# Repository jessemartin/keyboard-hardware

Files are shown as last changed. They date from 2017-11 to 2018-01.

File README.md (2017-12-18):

Wireless Keyboard Project: Hardware
===================================

These are [Eagle](https://www.autodesk.com/products/eagle/overview) design files for PCBs used in my wireless keyboard project.

Engineering Overview
--------------------
Each keyboard section runs a [Nordic nRF51822](https://www.nordicsemi.com/eng/Products/Bluetooth-low-energy/nRF51822) in the [Waveshare core51822-b](https://www.waveshare.com/core51822-b.htm) package, powered by a lithium ion battery.

Instead of using a traditional matrix that requires constant scanning (and thereby constant power usage), each key is connected to its own dedicated pin. This way, the chip can enter sleep until interrupted by a key press.

When a key press occurs, it is first debounced to prevent the mechanical switch from generating extra key presses. After that, the pressed keys are collected and transmitted through the [Gazell protocol](https://infocenter.nordicsemi.com/index.jsp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) to the receiver.

The receiver transforms the pressed keys into a matrix and passes that off the the [ATmega32U4 Pro Micro](https://www.sparkfun.com/products/12640), which runs [QMK firmware](https://github.com/qmk/qmk_firmware/). The Pro Micro sends the signal over USB to the computer as input.

Keyboard Layout
---------------
http://www.keyboard-layout-editor.com/#/gists/4d522280e8e3315902466de2c982f663
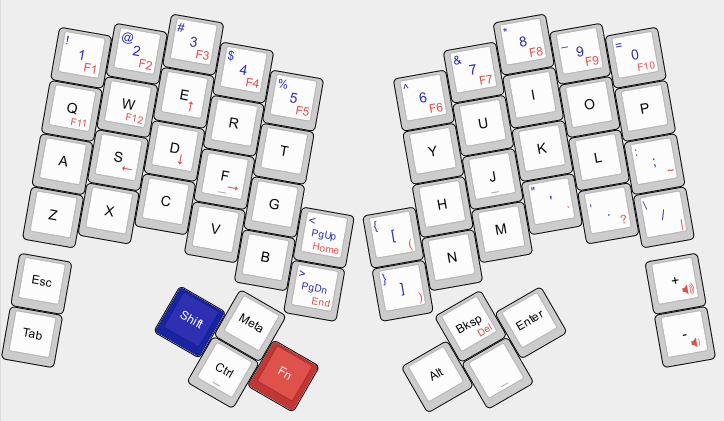
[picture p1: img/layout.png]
Layout


Folder Structure
----------------
 - `3d` contains [SketchUp](https://app.sketchup.com/app) renderings of what the final product could look like. These are not dimensionally accurate.
 - `fab` contains design rules and CAM settings for [DirtyPCBs](https://dirtypcbs.com/store/pcbs) and [OSH Park](https://oshpark.com/)
 - `lib` contains device libraries that are used by the `receiver` and `keyboard` projects.

PCB Fab Specifications
----------------------
* FR4 fiberglass
* 2 layer
* 1.6mm thickness

Keyboard PCBs
-------------

A single, reversible board is used for each keyboard half. The top of the board is used for the left half, and the bottom for the right half:

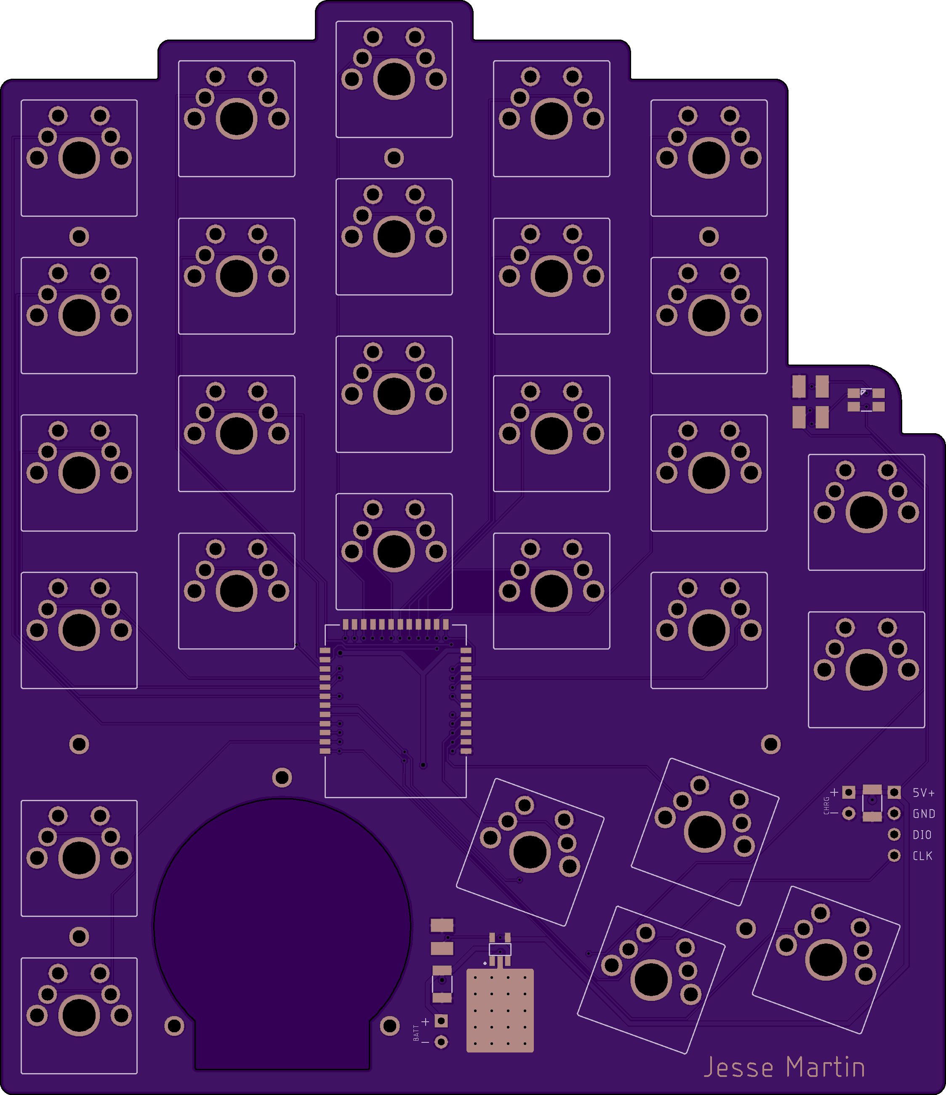
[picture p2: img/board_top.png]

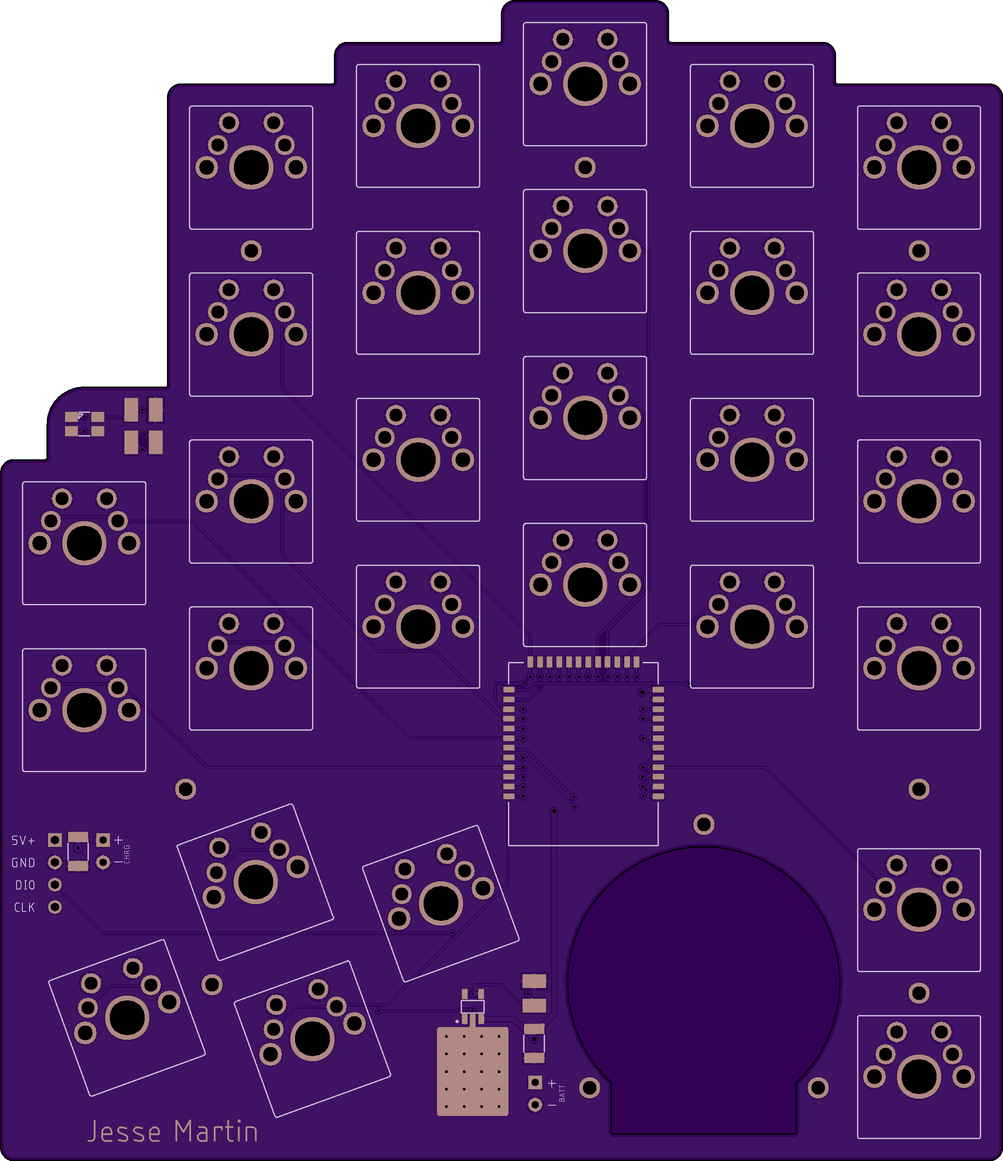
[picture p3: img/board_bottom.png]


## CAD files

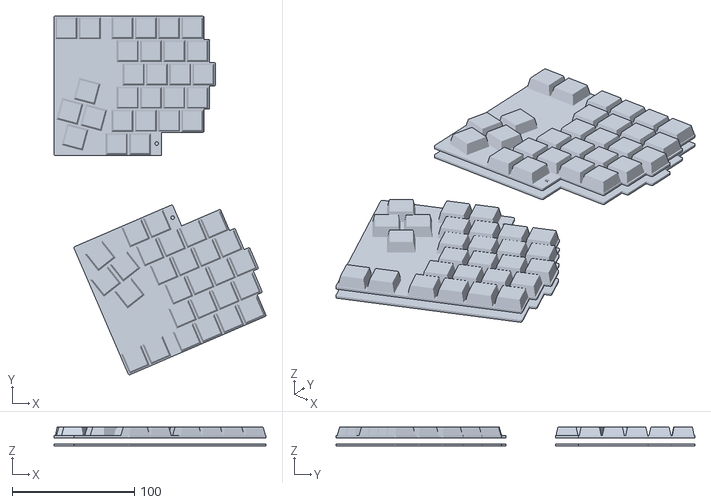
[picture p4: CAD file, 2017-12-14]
3d/keyboard.stl
173.2 x 293.2 x 15.3

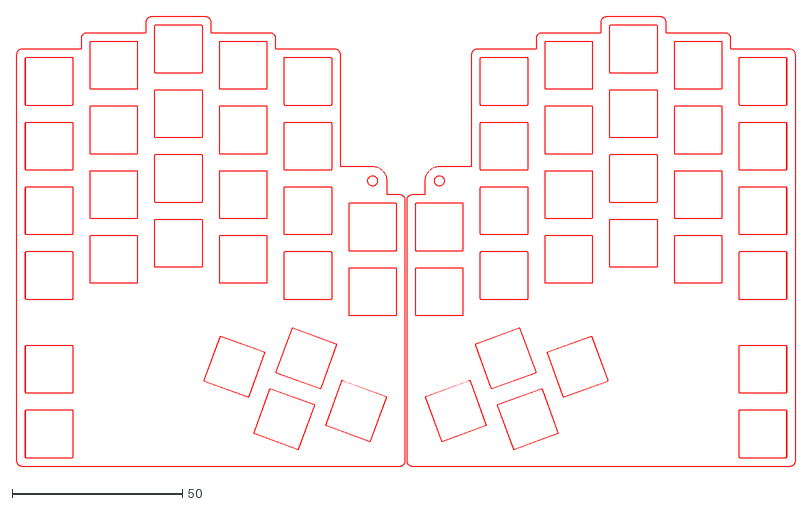
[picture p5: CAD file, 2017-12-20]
keyboard/plate.dxf
228.8 x 132.2

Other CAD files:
3d/keyboard.skp

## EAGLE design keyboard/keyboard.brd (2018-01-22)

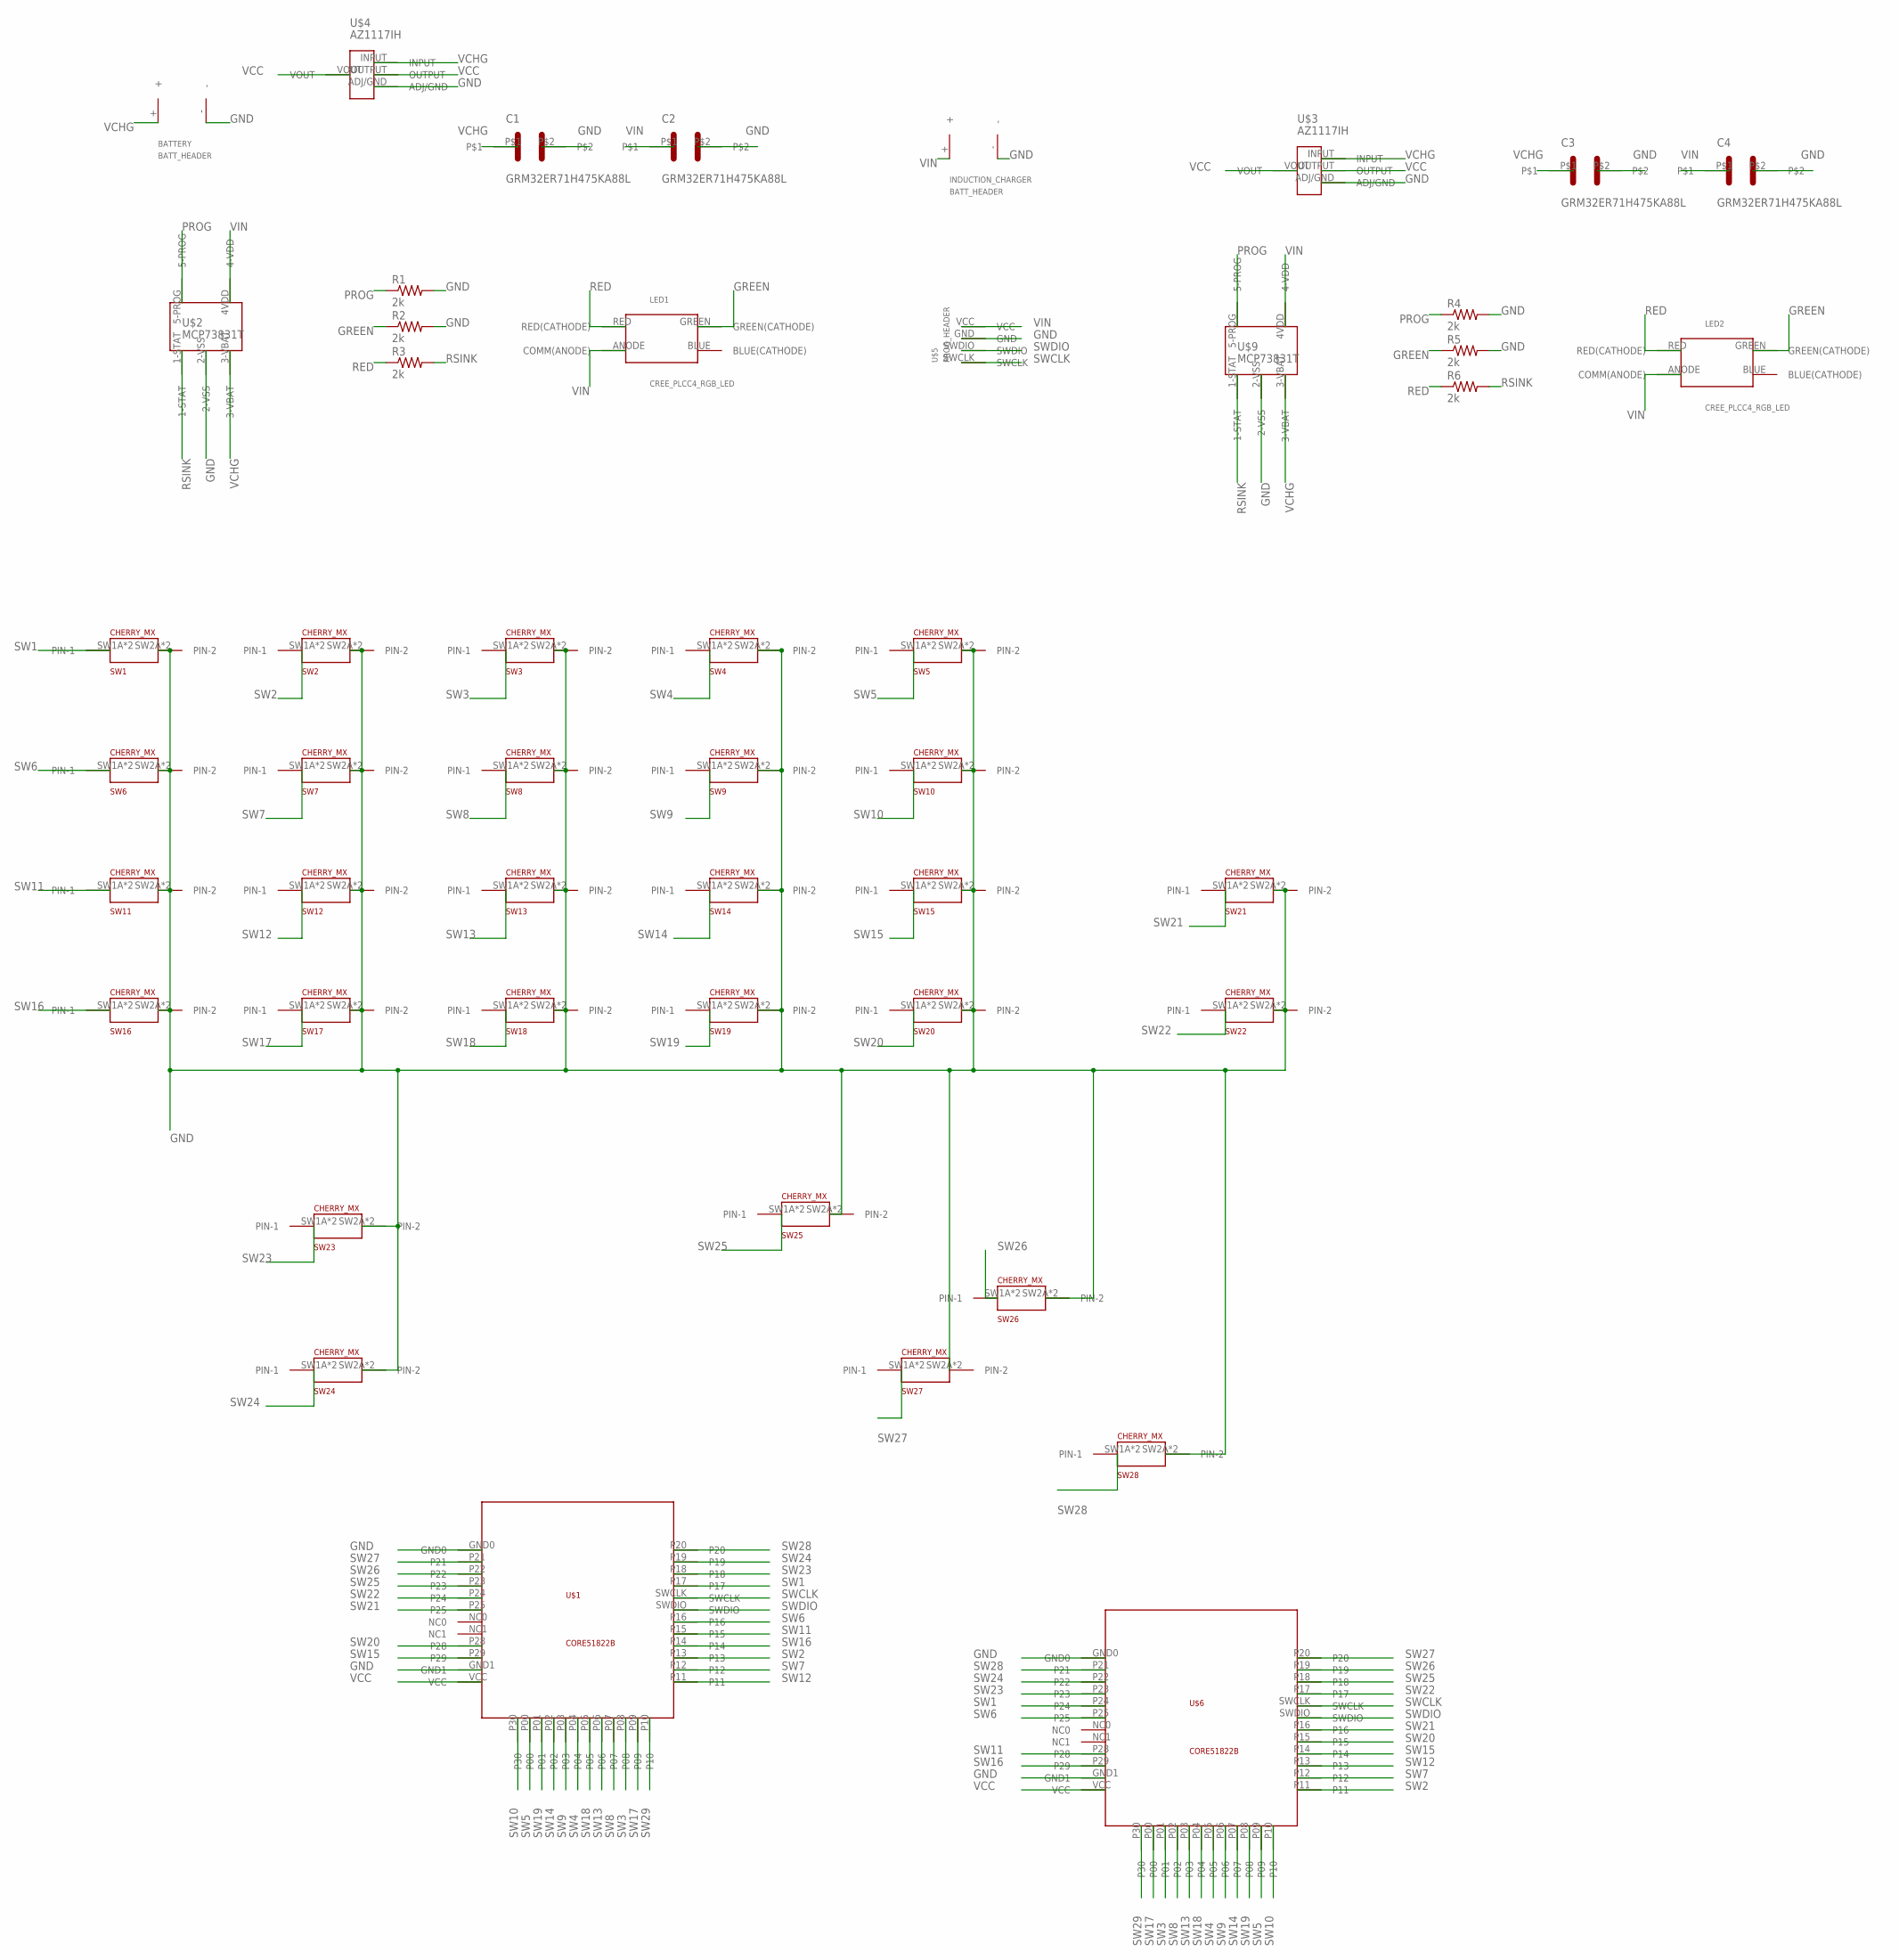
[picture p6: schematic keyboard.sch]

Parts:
BATTERY: BATT_HEADER
C1, C2, C3, C4: GRM32ER71H475KA88L
INDUCTION_CHARGER: BATT_HEADER
LED1, LED2: CREE_PLCC4_RGB_LED; 4-PLCC
R1, R2, R3, R4, R5, R6: 2k; R1210
SW1, SW2, SW3, SW4, SW5, SW6, SW7, SW8, SW9, SW10, SW11, SW12, SW13, SW14, SW15, SW16, SW17, SW18, SW19, SW20, SW21, SW22, SW23, SW24, SW25, SW26, SW27, SW28: CHERRY_MX
U$1, U$6: CORE51822B
U$2, U$9: MCP73831T
U$3, U$4: AZ1117IH
U$5: PROG_HEADER

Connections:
GND: BATTERY.-, C1.P$2, C2.P$2, C3.P$2, C4.P$2, INDUCTION_CHARGER.-, R1.2, R2.2, R4.2, R5.2, SW1.SW2A (PIN-2), SW1.SW2B (PIN-2), SW2.SW2A (PIN-2), SW2.SW2B (PIN-2), SW3.SW2A (PIN-2), SW3.SW2B (PIN-2), SW4.SW2A (PIN-2), SW4.SW2B (PIN-2), SW5.SW2A (PIN-2), SW5.SW2B (PIN-2), SW6.SW2A (PIN-2), SW6.SW2B (PIN-2), SW7.SW2A (PIN-2), SW7.SW2B (PIN-2), SW8.SW2A (PIN-2), SW8.SW2B (PIN-2), SW9.SW2A (PIN-2), SW9.SW2B (PIN-2), SW10.SW2A (PIN-2), SW10.SW2B (PIN-2), SW11.SW2A (PIN-2), SW11.SW2B (PIN-2), SW12.SW2A (PIN-2), SW12.SW2B (PIN-2), SW13.SW2A (PIN-2), SW13.SW2B (PIN-2), SW14.SW2A (PIN-2), SW14.SW2B (PIN-2), SW15.SW2A (PIN-2), SW15.SW2B (PIN-2), SW16.SW2A (PIN-2), SW16.SW2B (PIN-2), SW17.SW2A (PIN-2), SW17.SW2B (PIN-2), SW18.SW2A (PIN-2), SW18.SW2B (PIN-2), SW19.SW2A (PIN-2), SW19.SW2B (PIN-2), SW20.SW2A (PIN-2), SW20.SW2B (PIN-2), SW21.SW2A (PIN-2), SW21.SW2B (PIN-2), SW22.SW2A (PIN-2), SW22.SW2B (PIN-2), SW23.SW2A (PIN-2), SW23.SW2B (PIN-2), SW24.SW2A (PIN-2), SW24.SW2B (PIN-2), SW25.SW2A (PIN-2), SW25.SW2B (PIN-2), SW26.SW2A (PIN-2), SW26.SW2B (PIN-2), SW27.SW2A (PIN-2), SW27.SW2B (PIN-2), SW28.SW2A (PIN-2), SW28.SW2B (PIN-2), U$1.GND0, U$1.GND1, U$2.2-VSS, U$3.ADJ/GND, U$4.ADJ/GND, U$5.GND, U$6.GND0, U$6.GND1, U$9.2-VSS
GREEN: LED1.GREEN (GREEN(CATHODE)), LED2.GREEN (GREEN(CATHODE)), R2.1, R5.1
PROG: R1.1, R4.1, U$2.5-PROG, U$9.5-PROG
RED: LED1.RED (RED(CATHODE)), LED2.RED (RED(CATHODE)), R3.1, R6.1
RSINK: R3.2, R6.2, U$2.1-STAT, U$9.1-STAT
SW1: SW1.SW1A (PIN-1), SW1.SW1B (PIN-1), U$1.P17, U$6.P24
SW2: SW2.SW1A (PIN-1), SW2.SW1B (PIN-1), U$1.P13, U$6.P11
SW3: SW3.SW1A (PIN-1), SW3.SW1B (PIN-1), U$1.P08, U$6.P01
SW4: SW4.SW1A (PIN-1), SW4.SW1B (PIN-1), U$1.P04, U$6.P05
SW5: SW5.SW1A (PIN-1), SW5.SW1B (PIN-1), U$1.P00, U$6.P09
SW6: SW6.SW1A (PIN-1), SW6.SW1B (PIN-1), U$1.P16, U$6.P25
SW7: SW7.SW1A (PIN-1), SW7.SW1B (PIN-1), U$1.P12, U$6.P12
SW8: SW8.SW1A (PIN-1), SW8.SW1B (PIN-1), U$1.P07, U$6.P02
SW9: SW9.SW1A (PIN-1), SW9.SW1B (PIN-1), U$1.P03, U$6.P06
SW10: SW10.SW1A (PIN-1), SW10.SW1B (PIN-1), U$1.P30, U$6.P10
SW11: SW11.SW1A (PIN-1), SW11.SW1B (PIN-1), U$1.P15, U$6.P28
SW12: SW12.SW1A (PIN-1), SW12.SW1B (PIN-1), U$1.P11, U$6.P13
SW13: SW13.SW1A (PIN-1), SW13.SW1B (PIN-1), U$1.P06, U$6.P03
SW14: SW14.SW1A (PIN-1), SW14.SW1B (PIN-1), U$1.P02, U$6.P07
SW15: SW15.SW1A (PIN-1), SW15.SW1B (PIN-1), U$1.P29, U$6.P14
SW16: SW16.SW1A (PIN-1), SW16.SW1B (PIN-1), U$1.P14, U$6.P29
SW17: SW17.SW1A (PIN-1), SW17.SW1B (PIN-1), U$1.P09, U$6.P00
SW18: SW18.SW1A (PIN-1), SW18.SW1B (PIN-1), U$1.P05, U$6.P04
SW19: SW19.SW1A (PIN-1), SW19.SW1B (PIN-1), U$1.P01, U$6.P08
SW20: SW20.SW1A (PIN-1), SW20.SW1B (PIN-1), U$1.P28, U$6.P15
SW21: SW21.SW1A (PIN-1), SW21.SW1B (PIN-1), U$1.P25, U$6.P16
SW22: SW22.SW1A (PIN-1), SW22.SW1B (PIN-1), U$1.P24, U$6.P17
SW23: SW23.SW1A (PIN-1), SW23.SW1B (PIN-1), U$1.P18, U$6.P23
SW24: SW24.SW1A (PIN-1), SW24.SW1B (PIN-1), U$1.P19, U$6.P22
SW25: SW25.SW1A (PIN-1), SW25.SW1B (PIN-1), U$1.P23, U$6.P18
SW26: SW26.SW1A (PIN-1), SW26.SW1B (PIN-1), U$1.P22, U$6.P19
SW27: SW27.SW1A (PIN-1), SW27.SW1B (PIN-1), U$1.P21, U$6.P20
SW28: SW28.SW1A (PIN-1), SW28.SW1B (PIN-1), U$1.P20, U$6.P21
SW29: U$1.P10, U$6.P30
SWCLK: U$1.SWCLK, U$5.SWCLK, U$6.SWCLK
SWDIO: U$1.SWDIO, U$5.SWDIO, U$6.SWDIO
VCC: U$1.VCC, U$3.OUTPUT, U$3.VOUT, U$4.OUTPUT, U$4.VOUT, U$6.VCC
VCHG: BATTERY.+, C1.P$1, C3.P$1, U$2.3-VBAT, U$3.INPUT, U$4.INPUT, U$9.3-VBAT
VIN: C2.P$1, C4.P$1, INDUCTION_CHARGER.+, LED1.ANODE (COMM(ANODE)), LED2.ANODE (COMM(ANODE)), U$2.4VDD (4-VDD), U$5.VCC, U$9.4VDD (4-VDD)

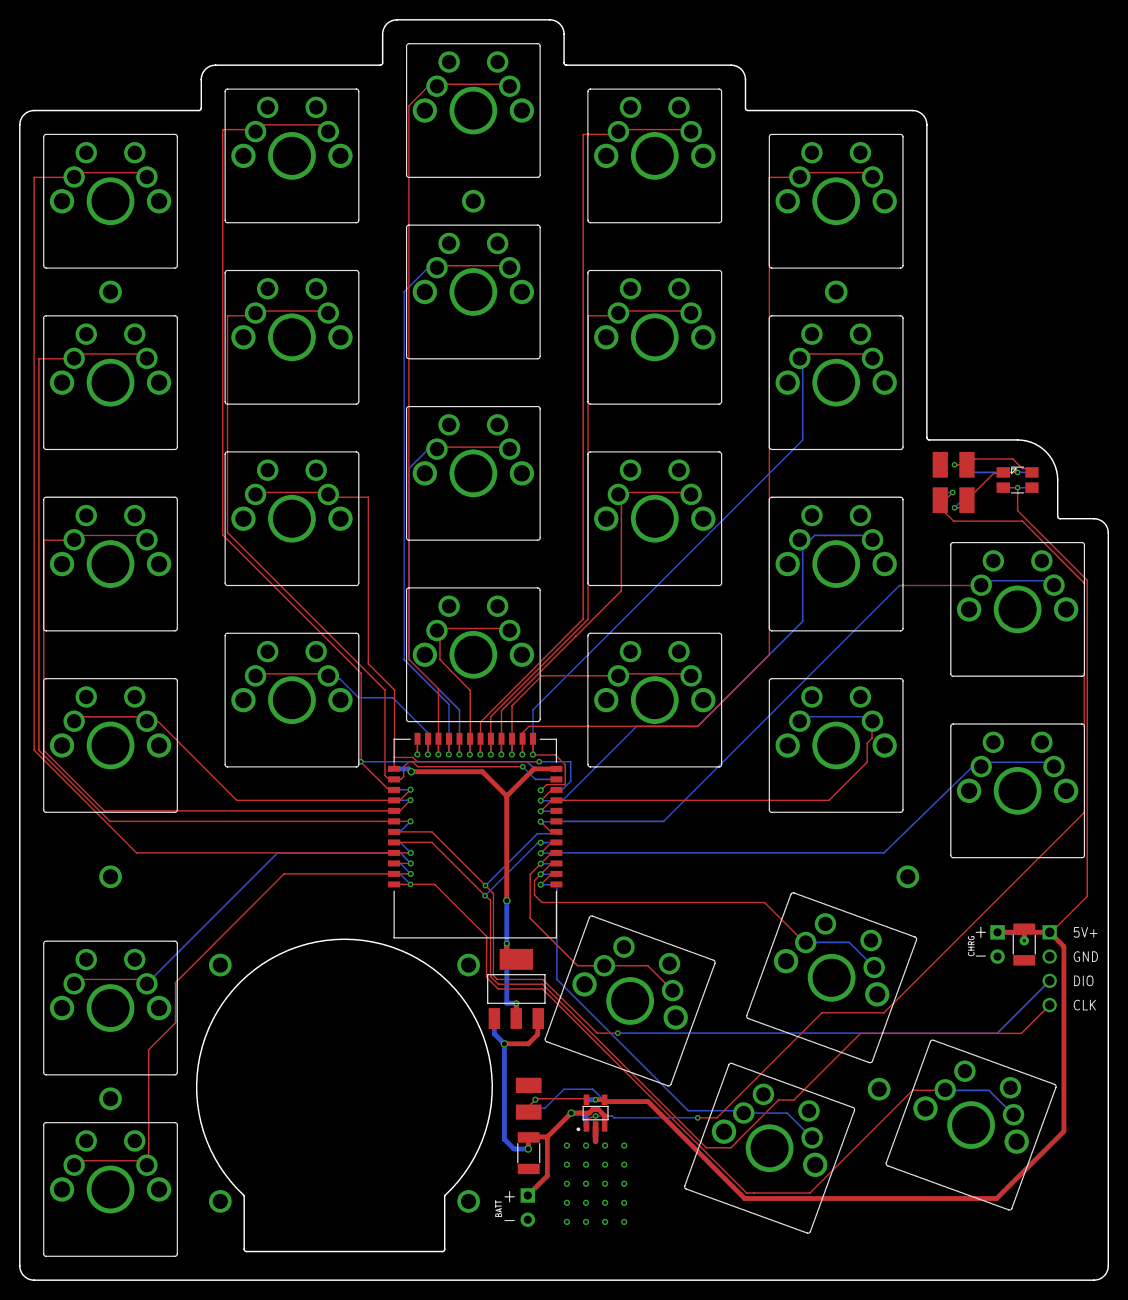
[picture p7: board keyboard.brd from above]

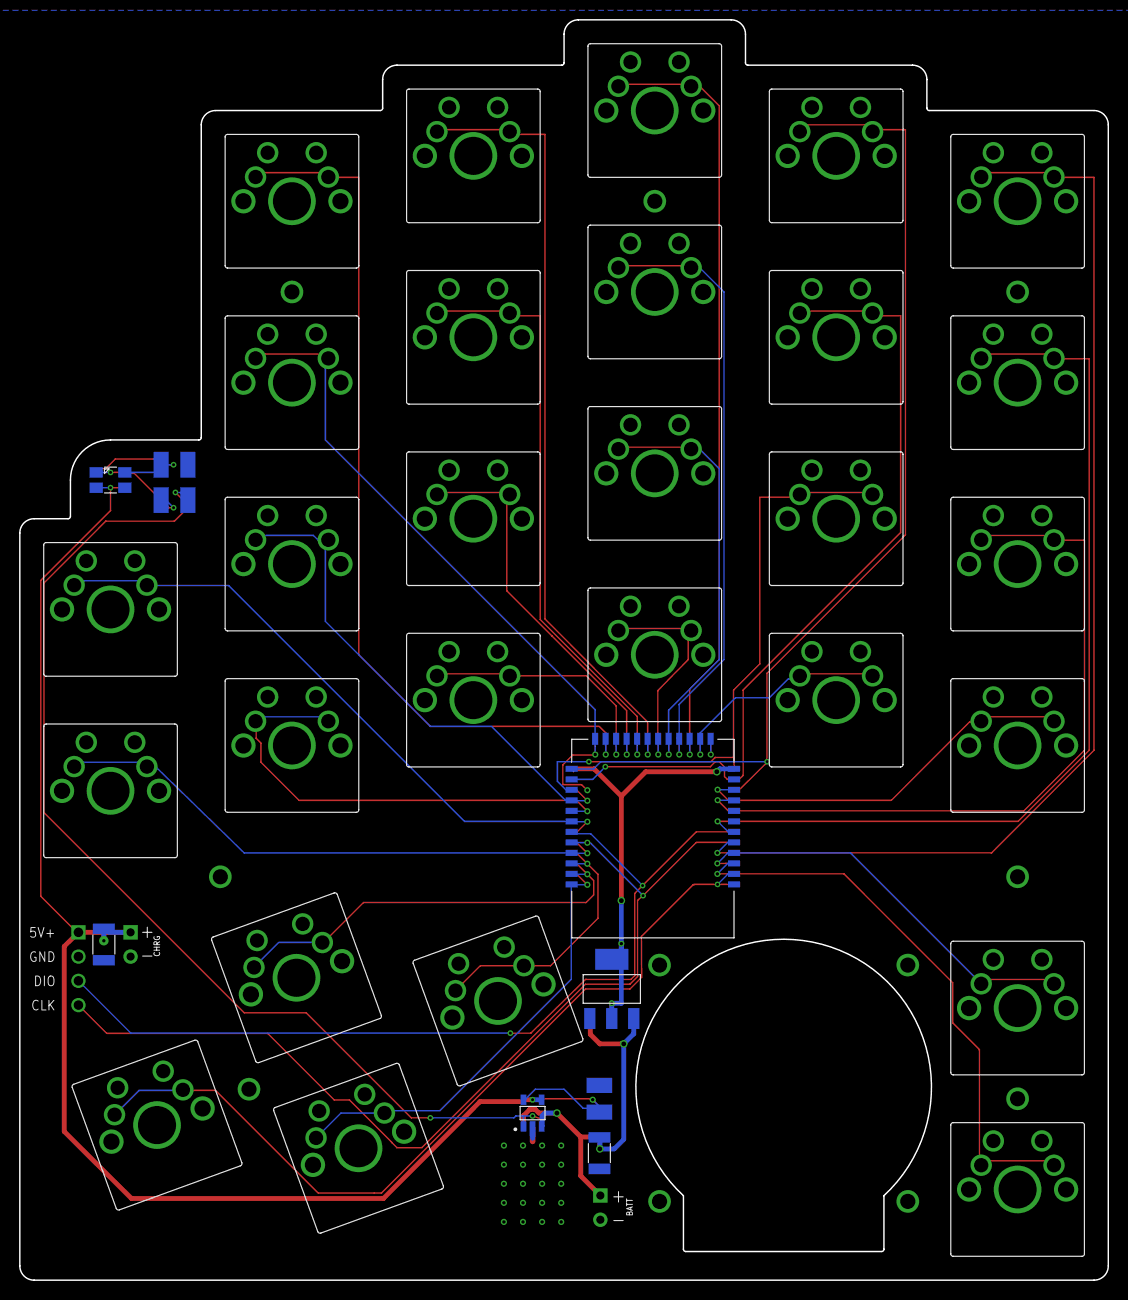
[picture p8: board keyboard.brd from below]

Board: 2 copper layers, 114.0 x 132.0 mm, 49 parts (9 on the bottom side), 39 nets.

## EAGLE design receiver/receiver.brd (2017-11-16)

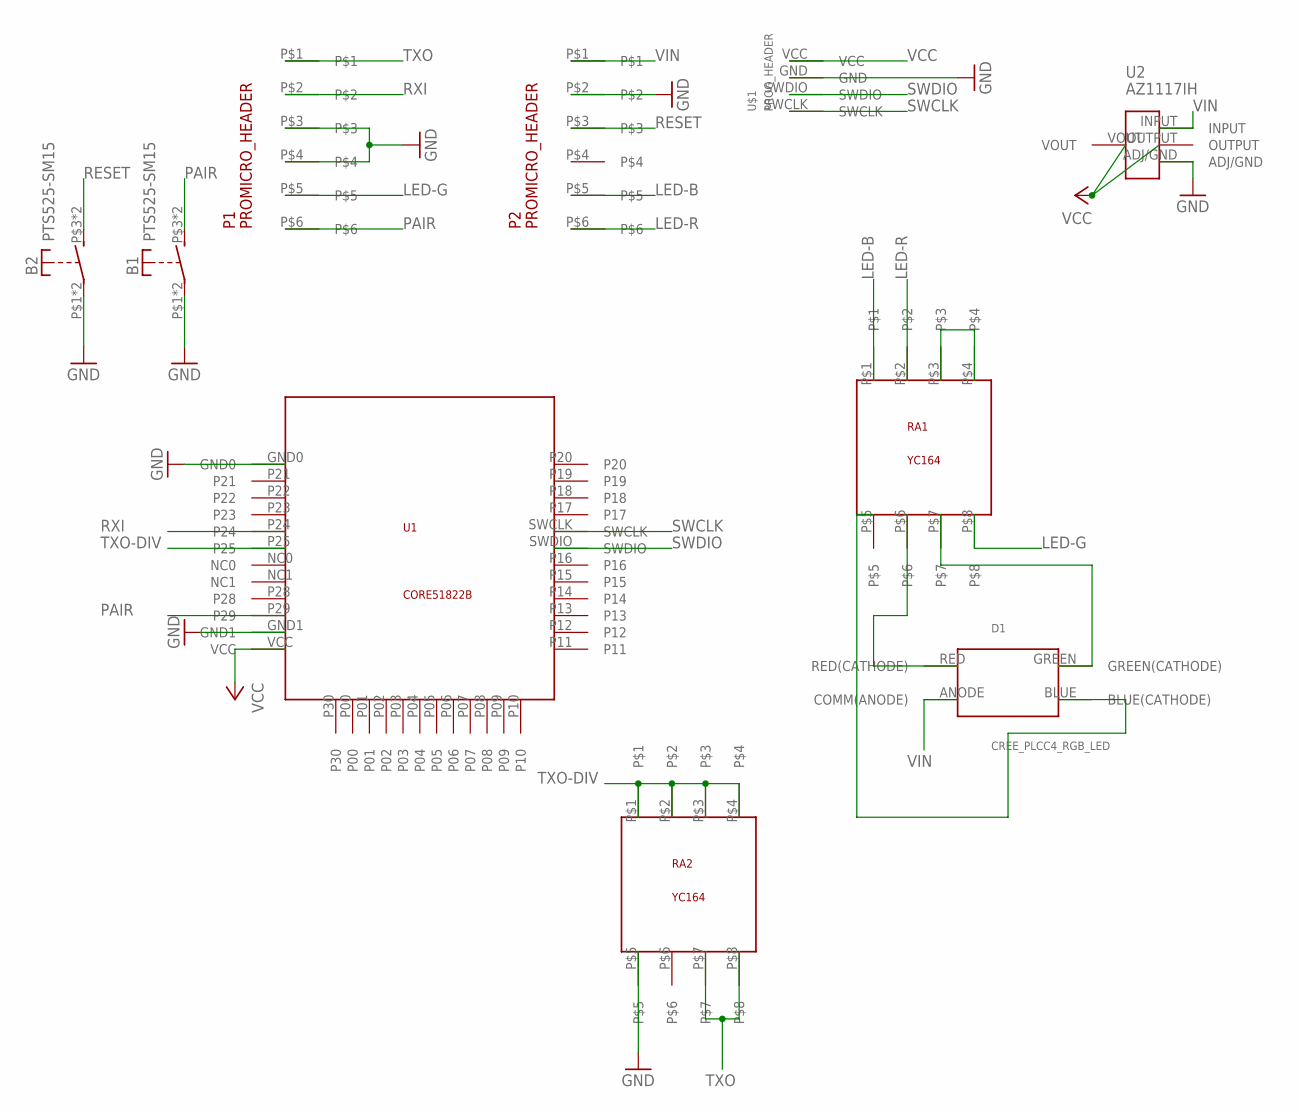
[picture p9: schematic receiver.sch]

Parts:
B1, B2: PTS525-SM15
D1: CREE_PLCC4_RGB_LED; 4-PLCC
P1, P2: PROMICRO_HEADER
RA1, RA2: YC164
U1: CORE51822B
U2: AZ1117IH
U$1: PROG_HEADER

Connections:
GND: B1.P$1, B1.P$2, B2.P$1, B2.P$2, P1.P$3, P1.P$4, P2.P$2, RA2.P$5, U1.GND0, U1.GND1, U2.ADJ/GND, U$1.GND
LED-B: P2.P$5, RA1.P$1
LED-G: P1.P$5, RA1.P$8
LED-R: P2.P$6, RA1.P$2
unnamed: RA1.P$3, RA1.P$4
unnamed: D1.GREEN (GREEN(CATHODE)), RA1.P$7
unnamed: D1.RED (RED(CATHODE)), RA1.P$6
unnamed: D1.BLUE (BLUE(CATHODE)), RA1.P$5
PAIR: B1.P$3 (S), B1.P$4 (S), P1.P$6, U1.P29
RESET: B2.P$3 (S), B2.P$4 (S), P2.P$3
RXI: P1.P$2, U1.P24
SWCLK: U1.SWCLK, U$1.SWCLK
SWDIO: U1.SWDIO, U$1.SWDIO
TXO: P1.P$1, RA2.P$7, RA2.P$8
TXO-DIV: RA2.P$1, RA2.P$2, RA2.P$3, RA2.P$4, U1.P25
VCC: U1.VCC, U2.OUTPUT, U2.VOUT, U$1.VCC
VIN: D1.ANODE (COMM(ANODE)), P2.P$1, U2.INPUT

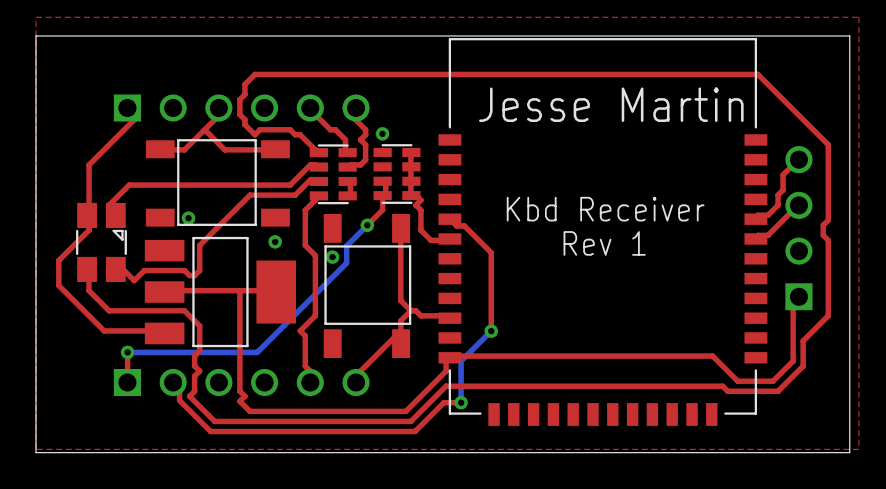
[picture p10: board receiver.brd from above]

Board: 2 copper layers, 45.2 x 23.1 mm, 10 parts (0 on the bottom side), 17 nets.

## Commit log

2017-11-09 add schematic and board
    [pro_micro.brd, pro_micro.sch]
2017-11-09 add receiver
    [pro_micro.brd, pro_micro.sch, receiver.brd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]
2017-11-09 finish core51822b device
2017-11-09 remove unfinished files
    [keyboard.brd, keyboard.sch]
2017-11-11 add yc164 resistor array
2017-11-11 add yc164 resistor to receiver
    [receiver.brd, receiver.sch]
2017-11-12 layout components
    [receiver.brd, receiver.sch]
2017-11-12 add pts525-sm15 spst push button switch
    [receiver.brd, receiver.sch]
2017-11-14 update board
    [receiver.brd, receiver.sch]
2017-11-14 include programming header on board
    [receiver.brd, receiver.sch]
2017-11-14 add switch tplace
    [receiver.brd, receiver.sch]
2017-11-14 add 2nd layer ground and vias
    [receiver.brd]
2017-11-15 finish routing vias
    [receiver.brd, receiver.sch]
2017-11-15 update led pin names
2017-11-15 update drill size to 10mil
    [receiver.brd, receiver.sch]
2017-11-15 reposition prog header
    [receiver.brd]
2017-11-16 generate gerbers
    [receiver.GBL, receiver.GBS, receiver.GTL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]
2017-11-16 revise board layout
    [receiver.brd, receiver.sch]
2017-11-16 generate v2 gerbers
    [receiver.GBL, receiver.GBS, receiver.GTL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]
2017-11-16 update silkscreen
    [receiver.brd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]
2017-11-16 include gerber zip
2017-11-16 generate dirtypcb gerbers
    [receiver.GBL, receiver.GBO, receiver.GBP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]
2017-11-18 cleanup gerbers
    [receiver.GBL, receiver.GBO, receiver.GBP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]
2017-12-05 add numpad
    [numpad.brd, numpad.sch]
2017-12-05 add keyboard
    [keyboard.brd, keyboard.sch]
2017-12-06 update numpad
    [numpad.brd]
2017-12-06 initial key layout
    [keyboard.brd, keyboard.sch]
2017-12-06 move header inward to allow for 90° bend
    [keyboard.brd]
2017-12-07 wire up switches
    [keyboard.brd, keyboard.sch]
2017-12-07 run autorouter
    [keyboard.brd]
2017-12-07 rearrange pins to eliminate vias
    [keyboard.brd, keyboard.sch]
2017-12-07 consistently align keys
    [keyboard.brd, keyboard.sch]
2017-12-07 add MCP73831T LiPo CMC
    [keyboard.brd, keyboard.sch]
2017-12-08 use pads for cherry mx mounting pins
    [keyboard.brd, keyboard.sch]
2017-12-08 connect mcp73831t charging circuit
    [keyboard.brd, keyboard.sch]
2017-12-10 update resistors
    [keyboard.brd, keyboard.sch]
2017-12-10 add GRM32ER71H475KA88L capacitor
    [keyboard.brd, keyboard.sch]
2017-12-10 mirror charging circuit on board bottom
    [keyboard.brd, keyboard.sch]
2017-12-10 smash labels and values
    [keyboard.brd]
2017-12-10 add induction charger header
    [keyboard.brd, keyboard.sch]
2017-12-11 finish routing
    [keyboard.brd, keyboard.sch]
2017-12-11 miter board corners
    [keyboard.brd]
2017-12-11 consolidate nrf51 nets
    [keyboard.brd]
2017-12-11 cleanup vias
    [keyboard.brd]
2017-12-11 update names
    [keyboard.brd, keyboard.sch]
2017-12-11 add more heatsink vias
    [keyboard.brd]
2017-12-12 create plate cutout file
    [keyboard.brd, keyboard.sch, plate.dxf]
2017-12-12 move nrf51 to accommodate battery
    [keyboard.brd, keyboard.sch]
2017-12-12 cleanup names and values
    [keyboard.brd, keyboard.sch]
2017-12-12 remove numpad
    [numpad.brd, numpad.sch]
2017-12-13 start minimizing footprint
    [keyboard.brd]
2017-12-13 standardize signal thickness
    [keyboard.brd]
2017-12-13 resize board
    [keyboard.brd]
2017-12-13 update board edge profile
    [keyboard.brd, keyboard.sch]
2017-12-13 update heatsink pad on mcp73831t
    [keyboard.brd, keyboard.sch]
2017-12-13 generate test gerbers
    [keyboard.GBL, keyboard.GBO, keyboard.GBP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]
2017-12-14 expose mcp73831t heatsink pad copper
    [keyboard.brd, keyboard.sch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]
2017-12-14 add rough, inaccurate 3d models
    [keyboard.skp, keyboard.stl]
2017-12-16 add header labels to board bottom
    [keyboard.brd]
2017-12-16 move battery hole to dimension layer
    [keyboard.brd]
2017-12-17 remove airwire
    [keyboard.brd]
2017-12-17 update routing for oshpark
    [keyboard.brd]
2017-12-17 add board images
2017-12-17 update gerbers
    [keyboard.brd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]
2017-12-17 cleanup trace and text
    [keyboard.brd]
2017-12-17 update cherrymx bPlace
    [keyboard.brd, keyboard.sch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]
2017-12-17 fix prog header stops
    [keyboard.brd, keyboard.sch]
2017-12-17 regenerate gerbers
    [keyboard.GBO, keyboard.GBS, keyboard.GTO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]
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2017-12-18 increase mcp73831t heatsink pad size
    [keyboard.brd, keyboard.sch]
2017-12-18 increase corner radii to 1.5mm
    [keyboard.brd]
2017-12-19 increase drill size
    [keyboard.brd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]
2017-12-19 increase vcc via size
    [keyboard.brd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]
2017-12-19 update stops
    [keyboard.brd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]
2017-12-19 update pads
    [keyboard.GBL, keyboard.GBO, keyboard.GBP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]
2017-12-19 redesign heatsink
    [keyboard.brd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]
2017-12-19 add mounting holes
    [keyboard.brd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]
2017-12-20 extend battery bay
    [keyboard.brd]
2017-12-20 add laser cut outline
    [keyboard.GBL, keyboard.GBO, keyboard.GBP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]
2017-12-20 adjust battery
    [keyboard.GBL, keyboard.GBO, keyboard.GBP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]
2017-12-20 update routing
    [keyboard.brd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]
2017-12-20 full size plate
    [plate.brd, plate.dxf]
2018-01-22 add voltage regulator
    [keyboard.GBL, keyboard.GBO, keyboard.GBP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]
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
